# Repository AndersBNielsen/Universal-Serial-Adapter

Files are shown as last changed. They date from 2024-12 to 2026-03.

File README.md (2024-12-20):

# Universal-Serial-Adapter

## Hackable USB-C UART RS232 Adapter

The **Universal Serial Adapter** is an open-source hardware project designed to bridge USB-C, RS232, and TTL communication. This fully assembled adapter is packed with features tailored for advanced prototyping, embedded development, and system debugging.  

Make one yourself or <a href="https://www.imania.dk/product_info.php?cPath=204&products_id=7224&language=en">buy one here</a>

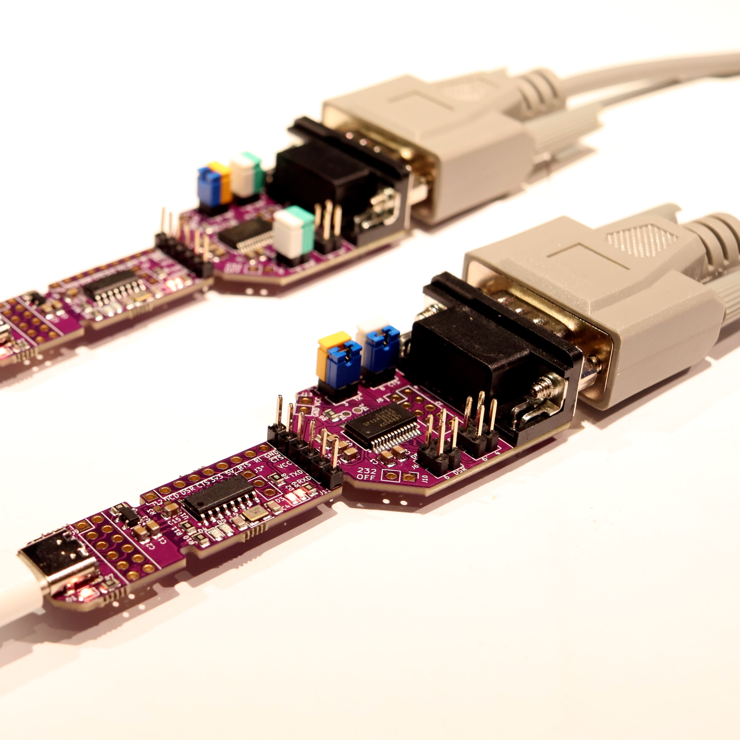
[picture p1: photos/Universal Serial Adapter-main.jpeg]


## **Technical Summary**  

### **Key Features**  
- **USB-C to RS232 Interface**  
  - USB-C (female) connector to DSUB9 RS232 (male) port.  
  - Supports bidirectional communication between modern USB-C devices and RS232 hardware.  

- **TTL Signal Breakouts**  
  - TTL RX, TX, and control signal pins exposed for easy interfacing with UART-based systems.  

- **Signal Polarity Configuration**  
  - RS232 RX, TX, and control signals configurable using 2.54mm header jumpers:  
    - **Horizontal jumper placement**: Straight connection.  
    - **Vertical jumper placement**: Crossed connection.  

- **USB-C Line Breakouts**  
  - Access to USB-C data lines for advanced custom applications.  

- **3.3V Linear Regulator**  
  - Integrated 3.3V linear regulator for powering external circuits.  

### **Core Components**  
- **WCH CH340G**: USB-to-UART bridge IC for reliable USB communication.  
- **SP3243**: TTL-to-RS232 transceiver IC for robust RS232 signaling.  

### **Customization and Modifications**  
- Advanced features such as additional breakout options or alternate configurations may require soldering or cutting traces on the PCB.  
- Preinstalled components include:  
  - USB-C connector  
  - DSUB9 RS232 connector  
  - UART header  
  - Configuration jumper blocks  
- Open to further modification for specific use cases.  

### **Open-Source Design**  
- Designed in **KiCAD 8**, with all source files available for inspection and modification.  
- Licensed under an open-source hardware license, encouraging collaboration and adaptation.  
- Repository includes:  
  - KiCAD design files.  
  - PCB layout and schematics.  
  - Bill of Materials (BOM).  

### **Applications**  
- Embedded system development.  
- Debugging and diagnostics of RS232 hardware.  
- Bridging modern USB-C devices to legacy RS232 systems.  

## **Repository Contents**  
- **/hardware/**: KiCAD project files for the PCB.  

## **Important Notes**  
- This adapter is a professional-grade tool and may require advanced soldering and modification skills for some features.  
- Enclosures, cables, and other accessories are not included.  

## **Get Started**  
Clone or download the repository to start customizing:  
```bash  
git clone https://github.com/AndersBNielsen/Universal-Serial-Adapter.git  
```
## Getting a PCB
This project is kindly sponsored by JLCPCB. They offer cheap, professional looking PCBs and super fast delivery.

Step 1: Get the gerber file zip package from the /hardware folder

Step 2: Upload to JLCPCB [https://jlcpcb.com](https://jlcpcb.com/?from=Anders_N)

Upload

Step 3: Pick your color, surface finish and order.

Select settings

Save your choice

If you want JLCPCB to assemble a board, the BOM and placement files are also in the repo. 

You can use these affiliate links to get a board for $2 and also get $60 worth of New User Coupons at: https://jlcpcb.com/?from=Anders_N

And in case you also want to order a 3D-printed case you can use this link. 
How to Get a $7 3D Printing Coupon: https://jlc3dp.com/?from=Anders_N

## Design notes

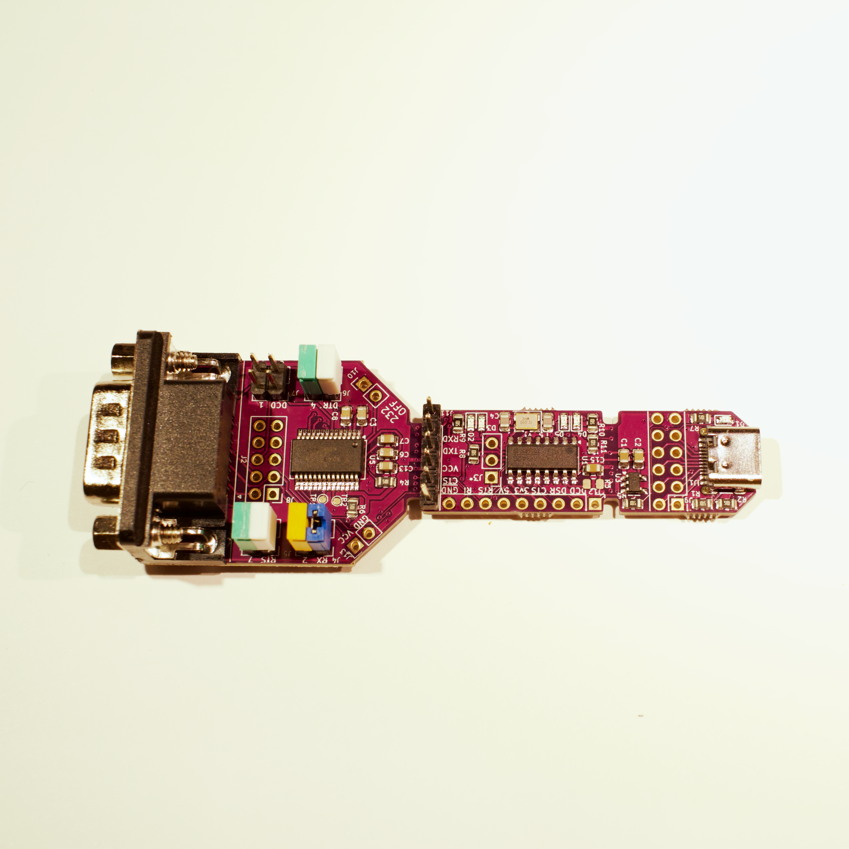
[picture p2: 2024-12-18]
photos/UniversalSerialAdapter-topflipped.jpeg

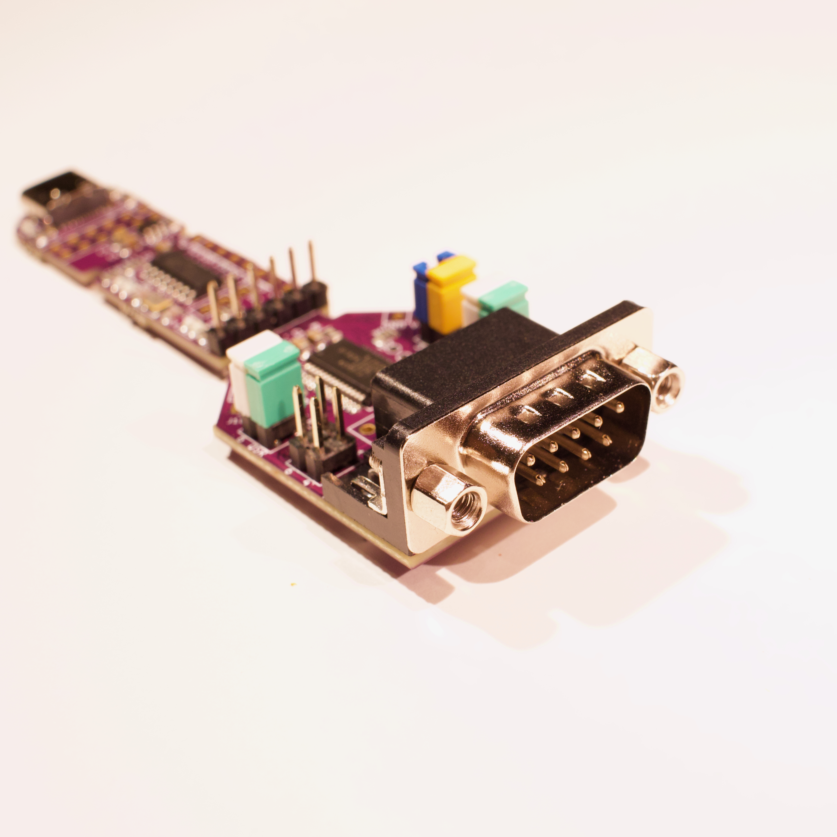
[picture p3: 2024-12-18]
photos/UniversalSerialAdapter-dsub9.jpeg

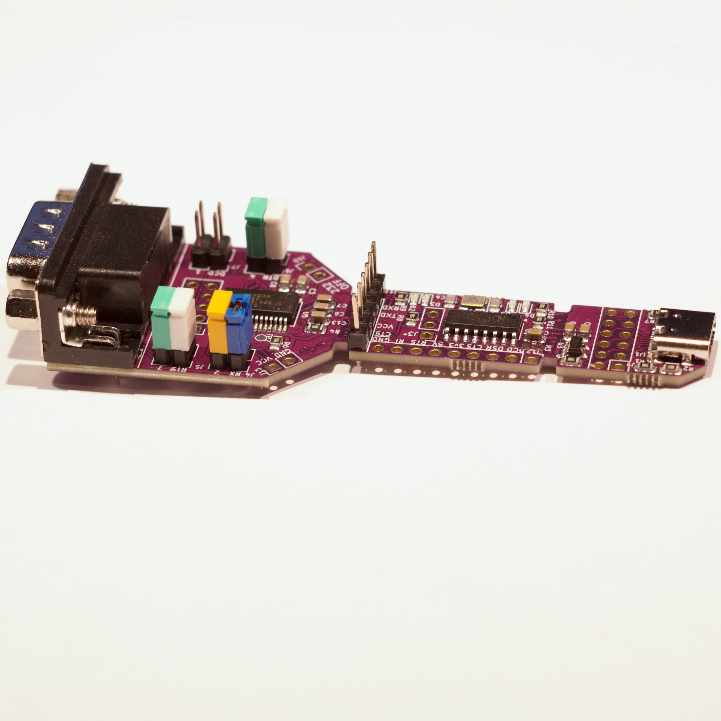
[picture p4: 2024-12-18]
photos/UniversalSerialAdapter-side.jpeg

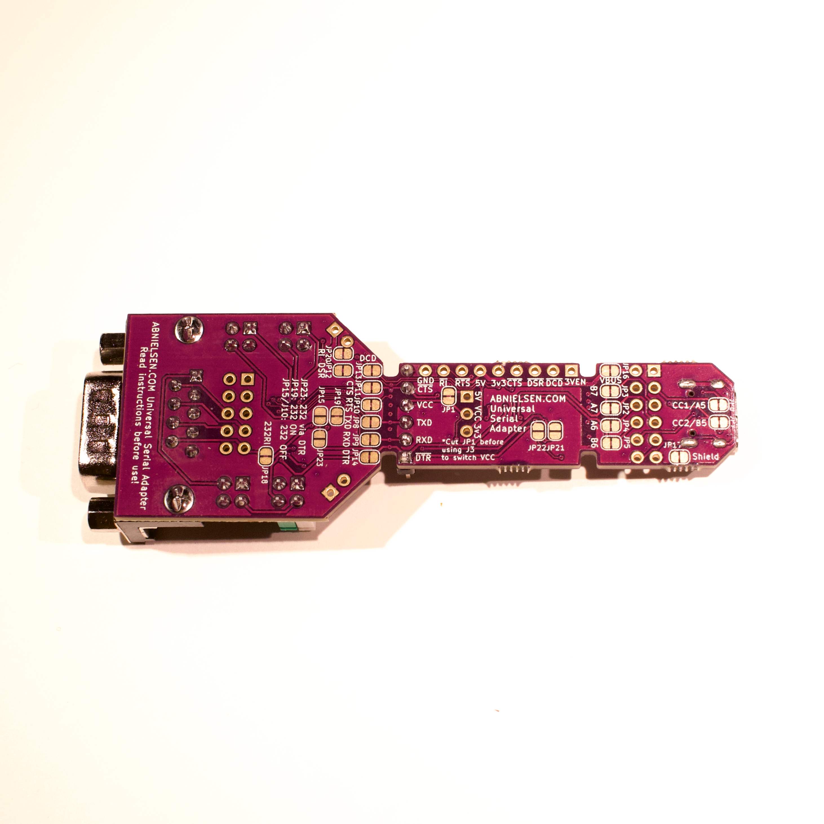
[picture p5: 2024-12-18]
photos/UniversalSerialAdapter-bottom.jpeg

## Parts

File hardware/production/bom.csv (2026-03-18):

Designator | Footprint | Quantity | Value | LCSC Part #
C1, C13, C15, C2, C3, C6, C7, C8 | 0805 | 8 | 1uF | C28323
C4, C5 | 0805 | 2 | 22p
D1 | 0603 | 1 | VBUS | C2286
D2 | 0603 | 1 | 3V3 | C2286
D3 | 0603 | 1 | VCC | C2286
D4 | 0603 | 1 | RXL | C2286
D5 | 0603 | 1 | TXL | C2286
J1 | USB_C_Receptacle_HCTL_HC-TYPE-C-16P-01A | 1 | HOST | C2894897
J11 | PinHeader_1x06_P2.54mm_Vertical | 1 | FTDI_HEADER | C37208
J13 | PinHeader_1x02_P2.54mm_Vertical | 1 | EXT_PWR
J2 | DSUB-9_Female_Horizontal_P2.77x2.84mm_EdgePinOffset7.70mm_Housed_MountingHolesOffset9.12mm | 1 | DE9_Receptacle | C19077344
J4 | PinHeader_2x02_P2.54mm_Vertical | 1 | RXTX | C492419
J5 | PinHeader_2x02_P2.54mm_Vertical | 1 | RTSCTS | C492419
J6 | PinHeader_2x02_P2.54mm_Vertical | 1 | DTRDSR | C492419
J7 | PinHeader_2x02_P2.54mm_Vertical | 1 | DCD | C492419
R1, R10, R11, R2, R4, R5, R6, R7, R8, R9 | 0805 | 10 | 5k1
TP1, TP2 | TestPoint_Pad_D1.0mm | 2 | TestPoint
U1 | SOIC-16_3.9x9.9mm_P1.27mm | 1 | CH340G | C14267
U3 | SOT-23-5 | 1 | MIC5504-3.3YM5 | C2832127
U5 | SSOP-28_5.3x10.2mm_P0.65mm | 1 | SP3243EUCY | C916165
Y1 | Crystal_SMD_3225-4Pin_3.2x2.5mm | 1 | 12MHz | C133334

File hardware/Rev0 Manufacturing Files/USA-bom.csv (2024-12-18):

Reference | Value | Datasheet | Footprint | Qty | DNP | LCSC
C1,C2,C3,C6,C7,C8,C13,C15 | 1uF | ~ | Capacitor_SMD:C_0805_2012Metric | 8 |  | C28323
C4,C5 | 22p | ~ | Capacitor_SMD:C_0805_2012Metric | 2
D1 | VBUS | ~ | LED_SMD:LED_0603_1608Metric | 1 |  | C2286
D2 | 3V3 | ~ | LED_SMD:LED_0603_1608Metric | 1 |  | C2286
D3 | VCC | ~ | LED_SMD:LED_0603_1608Metric | 1 |  | C2286
D4 | RXL | ~ | LED_SMD:LED_0603_1608Metric | 1 |  | C2286
D5 | TXL | ~ | LED_SMD:LED_0603_1608Metric | 1 |  | C2286
J1 | USB_C_Receptacle_USB2.0_16P | https://www.usb.org/sites/default/files/documents/usb_type-c.zip | Connector_USB:USB_C_Receptacle_HCTL_HC-TYPE-C-16P-01A | 1 |  | C2894897
J2 | DE9_Receptacle | ~ | Connector_Dsub:DSUB-9_Female_Horizontal_P2.77x2.84mm_EdgePinOffset7.70mm_Housed_MountingHolesOffset9.12mm | 1 |  | C19077344
J3,J8,J9,J10,J12,J13,R3 | NC | ~ | -- mixed values -- | 7
J4 | RXTX | ~ | Connector_PinHeader_2.54mm:PinHeader_2x02_P2.54mm_Vertical | 1 |  | C492419
J5 | RTSCTS | ~ | Connector_PinHeader_2.54mm:PinHeader_2x02_P2.54mm_Vertical | 1 |  | C492419
J6 | DTRDSR | ~ | Connector_PinHeader_2.54mm:PinHeader_2x02_P2.54mm_Vertical | 1 |  | C492419
J7 | DCD | ~ | Connector_PinHeader_2.54mm:PinHeader_2x02_P2.54mm_Vertical | 1 |  | C492419
J11 | UART | ~ | Connector_PinHeader_2.54mm:PinHeader_1x06_P2.54mm_Vertical | 1
R1,R2,R4,R5,R6,R7,R8,R9,R10,R11 | 5k1 | ~ | Resistor_SMD:R_0805_2012Metric | 10
TP1,TP2 | TestPoint | ~ | TestPoint:TestPoint_Pad_D1.0mm | 2
U1 | CH340G | http://www.datasheet5.com/pdf-local-2195953 | Package_SO:SOIC-16_3.9x9.9mm_P1.27mm | 1 |  | C14267
U3 | MIC5504-3.3YM5 | http://ww1.microchip.com/downloads/en/DeviceDoc/MIC550X.pdf | Package_TO_SOT_SMD:SOT-23-5 | 1 |  | C2832127
U5 | SP3243EUCY |  | Package_SO:SSOP-28_5.3x10.2mm_P0.65mm | 1 |  | C916165
Y1 | 12MHz | ~ | Crystal:Crystal_SMD_3225-4Pin_3.2x2.5mm | 1 |  | C133334

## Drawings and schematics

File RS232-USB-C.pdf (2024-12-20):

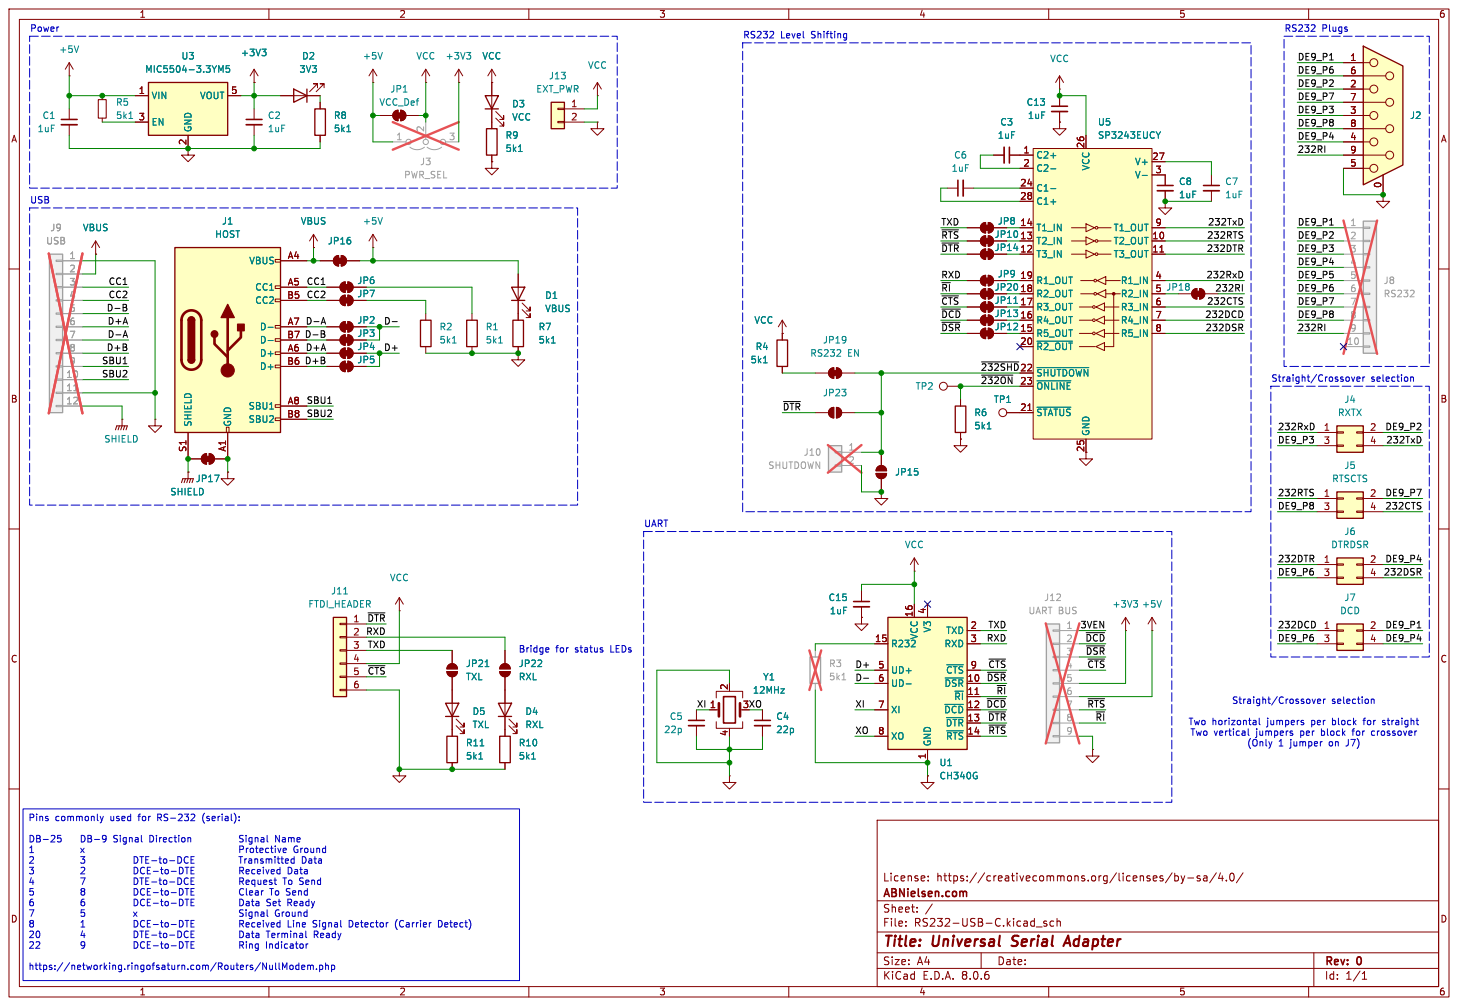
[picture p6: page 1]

4 UD+ 5 UD- 6 XI 7 XO 8 ~{CTS}9 Y1

1 ~{DSR} 10 ~{RI} 11 ~{DCD} 12 ~{DTR} 13 ~{RTS} 14 R232 15 VCC 16 TXD 2 RXD 3 V3

4 UD+ 5 UD- 6 XI 7 XO 8 ~{CTS}9 U1 CH340G

License: https://creativecommons.org/licenses/by-sa/4.0/
Id: 1/1 Title: Universal Serial Adapter File: RS232-USB-C.kicad_sch Sheet: / ABNielsen.com

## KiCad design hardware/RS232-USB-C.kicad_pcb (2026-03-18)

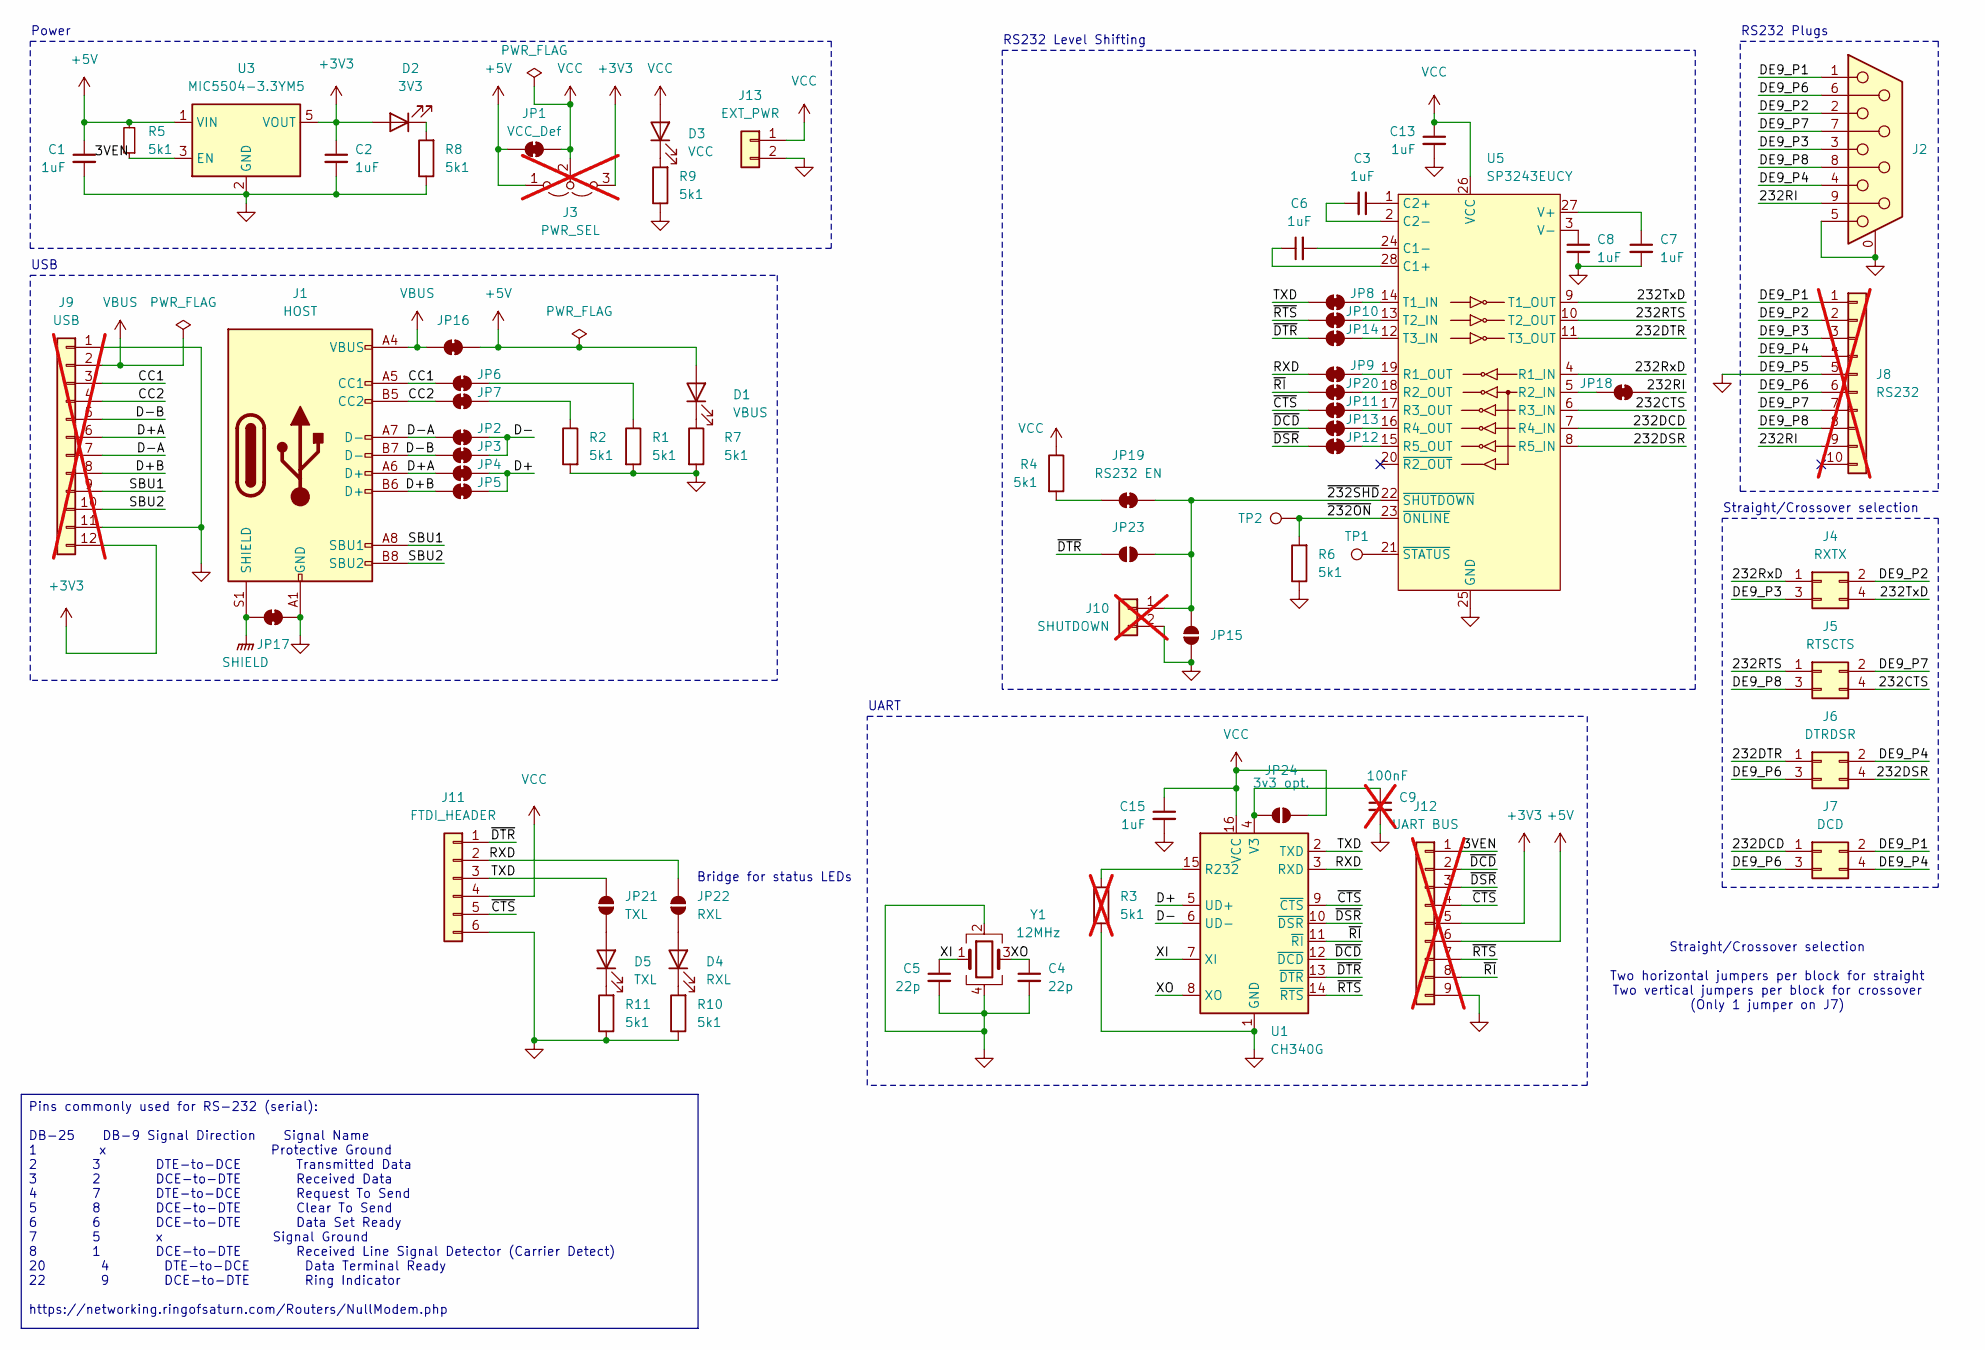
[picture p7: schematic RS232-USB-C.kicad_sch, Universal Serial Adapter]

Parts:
C1, C2, C3, C6, C7, C8, C13, C15: 1uF; C_0805_2012Metric; LCSC C28323
C4, C5: 22p; C_0805_2012Metric
C9: 100nF; C_0805_2012Metric; LCSC C28323; not fitted
D1: VBUS; LED_0603_1608Metric; LCSC C2286
D2: 3V3; LED_0603_1608Metric; LCSC C2286
D3: VCC; LED_0603_1608Metric; LCSC C2286
D4: RXL; LED_0603_1608Metric; LCSC C2286
D5: TXL; LED_0603_1608Metric; LCSC C2286
J1: HOST; USB_C_Receptacle_HCTL_HC-TYPE-C-16P-01A; LCSC C2894897
J2: DE9_Receptacle; DSUB-9_Female_Horizontal_P2.77x2.84mm_EdgePinOffset7.70mm_H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; LCSC C19077344
J3: PWR_SEL; PinHeader_1x03_P2.54mm_Vertical; not fitted
J4: RXTX; PinHeader_2x02_P2.54mm_Vertical; LCSC C492419
J5: RTSCTS; PinHeader_2x02_P2.54mm_Vertical; LCSC C492419
J6: DTRDSR; PinHeader_2x02_P2.54mm_Vertical; LCSC C492419
J7: DCD; PinHeader_2x02_P2.54mm_Vertical; LCSC C492419
J8: RS232; PinHeader_2x05_P2.54mm_Vertical; not fitted
J9: USB; PinHeader_2x06_P2.54mm_Vertical; not fitted
J10: SHUTDOWN; PinHeader_1x02_P2.54mm_Vertical; not fitted
J11: FTDI_HEADER; PinHeader_1x06_P2.54mm_Vertical; LCSC C37208
J12: UART BUS; PinHeader_1x09_P2.54mm_Vertical; not fitted
J13: EXT_PWR; PinHeader_1x02_P2.54mm_Vertical
JP1: VCC_Def; SolderJumper-2_P1.3mm_Bridged_RoundedPad1.0x1.5mm
JP2: A7; SolderJumper-2_P1.3mm_Bridged_RoundedPad1.0x1.5mm
JP3: B7; SolderJumper-2_P1.3mm_Bridged_RoundedPad1.0x1.5mm
JP4: A6; SolderJumper-2_P1.3mm_Bridged_RoundedPad1.0x1.5mm
JP5: B6; SolderJumper-2_P1.3mm_Bridged_RoundedPad1.0x1.5mm
JP6: CC1/A5; SolderJumper-2_P1.3mm_Bridged_RoundedPad1.0x1.5mm
JP7: CC2/B5; SolderJumper-2_P1.3mm_Bridged_RoundedPad1.0x1.5mm
JP8: TXD; SolderJumper-2_P1.3mm_Bridged_RoundedPad1.0x1.5mm
JP9: RXD; SolderJumper-2_P1.3mm_Bridged_RoundedPad1.0x1.5mm
JP10: RTS; SolderJumper-2_P1.3mm_Bridged_RoundedPad1.0x1.5mm
JP11: CTS; SolderJumper-2_P1.3mm_Bridged_RoundedPad1.0x1.5mm
JP12: DSR; SolderJumper-2_P1.3mm_Bridged_RoundedPad1.0x1.5mm
JP13: DCD; SolderJumper-2_P1.3mm_Bridged_RoundedPad1.0x1.5mm
JP14: DTR; SolderJumper-2_P1.3mm_Bridged_RoundedPad1.0x1.5mm
JP15, JP23: RS232 Shutdown; SolderJumper-2_P1.3mm_Open_RoundedPad1.0x1.5mm
JP16: VBUS; SolderJumper-2_P1.3mm_Bridged_RoundedPad1.0x1.5mm
JP17: Shield; SolderJumper-2_P1.3mm_Bridged_RoundedPad1.0x1.5mm
JP18: 232RI; SolderJumper-2_P1.3mm_Bridged_RoundedPad1.0x1.5mm
JP19: RS232 EN; SolderJumper-2_P1.3mm_Bridged_RoundedPad1.0x1.5mm
JP20: RI; SolderJumper-2_P1.3mm_Bridged_RoundedPad1.0x1.5mm
JP21: TXL; SolderJumper-2_P1.3mm_Open_RoundedPad1.0x1.5mm
JP22: RXL; SolderJumper-2_P1.3mm_Open_RoundedPad1.0x1.5mm
JP24: 3v3 opt.; SolderJumper-2_P1.3mm_Open_RoundedPad1.0x1.5mm
R1, R2, R4, R5, R6, R7, R8, R9, R10, R11: 5k1; R_0805_2012Metric
R3: 5k1; R_0805_2012Metric; not fitted
TP1, TP2: TestPoint; TestPoint_Pad_D1.0mm
U1: CH340G; SOIC-16_3.9x9.9mm_P1.27mm; LCSC C14267
U3: MIC5504-3.3YM5; SOT-23-5; LCSC C2832127
U5: SP3243EUCY; SSOP-28_5.3x10.2mm_P0.65mm; LCSC C916165
Y1: 12MHz; Crystal_SMD_3225-4Pin_3.2x2.5mm; LCSC C133334

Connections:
+3V3: C2.1, D2.2 (A), J3.3 (B), J9.12, J12.5, U3.5 (VOUT)
+5V: C1.1, D1.2 (A), J3.1 (A), J12.6, JP1.1 (A), JP16.2 (B), R5.2, U3.1 (VIN)
/3VEN: J12.1, R5.1, U3.3 (EN)
/232CTS: J5.4, U5.6 (R3_IN)
/232DCD: J7.1, U5.7 (R4_IN)
/232DSR: J6.4, U5.8 (R5_IN)
/232DTR: J6.1, U5.11 (T3_OUT)
/232RI: J2.9, J8.9, JP18.2 (B)
/232RTS: J5.1, U5.10 (T2_OUT)
/232RxD: J4.1, U5.4 (R1_IN)
/232TxD: J4.4, U5.9 (T1_OUT)
/CC1: J1.A5 (CC1), J9.3, JP6.1 (A)
/CC2: J1.B5 (CC2), J9.4, JP7.2 (B)
/D+: JP4.2 (B), JP5.2 (B), U1.5 (UD+)
/D+A: J1.A6 (D+), J9.6, JP4.1 (A)
/D+B: J1.B6 (D+), J9.8, JP5.1 (A)
/D-: JP2.2 (B), JP3.2 (B), U1.6 (UD-)
/D-A: J1.A7 (D-), J9.7, JP2.1 (A)
/D-B: J1.B7 (D-), J9.5, JP3.1 (A)
/DE9_P1: J2.1, J7.2, J8.1
/DE9_P2: J2.2, J4.2, J8.2
/DE9_P3: J2.3, J4.3, J8.3
/DE9_P4: J2.4, J6.2, J7.4, J8.4
/DE9_P6: J2.6, J6.3, J7.3, J8.6
/DE9_P7: J2.7, J5.2, J8.7
/DE9_P8: J2.8, J5.3, J8.8
/RXD: J11.2, JP9.1 (A), JP22.1 (A), U1.3 (RXD)
/SBU1: J1.A8 (SBU1), J9.9
/SBU2: J1.B8 (SBU2), J9.10
/TXD: J11.3, JP8.1 (A), JP21.1 (A), U1.2 (TXD)
/XI: C5.1, U1.7 (XI), Y1.1
/XO: C4.1, U1.8 (XO), Y1.3
/~232ON: R6.2, TP2.1, U5.23 (~ONLINE)
/~232SHD: J10.1, JP15.2 (B), JP19.2 (B), JP23.1 (A), U5.22 (~SHUTDOWN)
/~CTS: J11.5, J12.4, JP11.1 (A), U1.9 (~CTS)
/~DCD: J12.2, JP13.1 (A), U1.12 (~DCD)
/~DSR: J12.3, JP12.1 (A), U1.10 (~DSR)
/~DTR: J11.1, JP14.1 (A), JP23.2 (B), U1.13 (~DTR)
/~RI: J12.8, JP20.1 (A), U1.11 (~RI)
/~RTS: J12.7, JP10.1 (A), U1.14 (~RTS)
GND: C1.2, C2.2, C4.2, C5.2, C7.2, C8.2, C9.2, C13.2, C15.2, J1.A1 (GND), J1.A12 (GND), J1.B1 (GND), J1.B12 (GND), J2.0 (PAD), J2.5, J8.5, J9.1, J9.11, J10.2, J11.6, J12.9, J13.2, JP15.1 (A), JP17.2 (B), R1.2, R2.2, R3.1, R6.1, R7.2, R8.1, R9.1, R10.1, R11.1, U1.1 (GND), U3.2 (GND), U5.25 (GND), Y1.2, Y1.4
unnamed: D1.1 (K), R7.1
unnamed: D2.1 (K), R8.2
unnamed: D3.1 (K), R9.2
unnamed: D4.2 (A), JP22.2 (B)
unnamed: D4.1 (K), R10.2
unnamed: D5.2 (A), JP21.2 (B)
unnamed: D5.1 (K), R11.2
unnamed: JP6.2 (B), R1.1
unnamed: JP7.1 (A), R2.1
unnamed: JP8.2 (B), U5.14 (T1_IN)
unnamed: JP9.2 (B), U5.19 (R1_OUT)
unnamed: JP10.2 (B), U5.13 (T2_IN)
unnamed: JP11.2 (B), U5.17 (R3_OUT)
unnamed: JP12.2 (B), U5.15 (R5_OUT)
unnamed: JP13.2 (B), U5.16 (R4_OUT)
unnamed: JP14.2 (B), U5.12 (T3_IN)
unnamed: JP18.1 (A), U5.5 (R2_IN)
unnamed: JP19.1 (A), R4.2
unnamed: JP20.2 (B), U5.18 (R2_OUT)
unnamed: C9.1, JP24.1 (A), U1.4 (V3)
unnamed: R3.2, U1.15 (R232)
unnamed: C6.1, U5.28 (C1+)
unnamed: C6.2, U5.24 (C1-)
unnamed: C3.1, U5.1 (C2+)
unnamed: C3.2, U5.2 (C2-)
unnamed: C7.1, U5.27 (V+)
unnamed: C8.1, U5.3 (V-)
unnamed: TP1.1, U5.21 (~STATUS)
SHIELD: J1.S1 (SHIELD), JP17.1 (A)
VBUS: J1.A4 (VBUS), J1.A9 (VBUS), J1.B4 (VBUS), J1.B9 (VBUS), J9.2, JP16.1 (A)
VCC: C13.1, C15.1, D3.2 (A), J3.2 (C), J11.4, J13.1, JP1.2 (B), JP24.2 (B), R4.1, U1.16 (VCC), U5.26 (VCC)

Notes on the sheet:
Bridge for status LEDs
Power
RS232 Plugs
Straight/Crossover selection Two horizontal jumpers per block for straight Two vertical jumpers per block for crossover (Only 1 jumper on J7)
UART
USB
Straight/Crossover selection
RS232 Level Shifting
Pins commonly used for RS-232 (serial): DB-25 DB-9 Signal Direction Signal Name 1 x Protective Ground 2 3 DTE-to-DCE Transmitted Data 3 2 DCE-to-DTE Received Data 4 7 DTE-to-DCE Request To Send 5 8 DCE-to-DTE Clear To Send 6 6 DCE-to-DTE Data Set Ready 7 5 x Signal Ground 8 1 DCE-to-DTE Received Li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

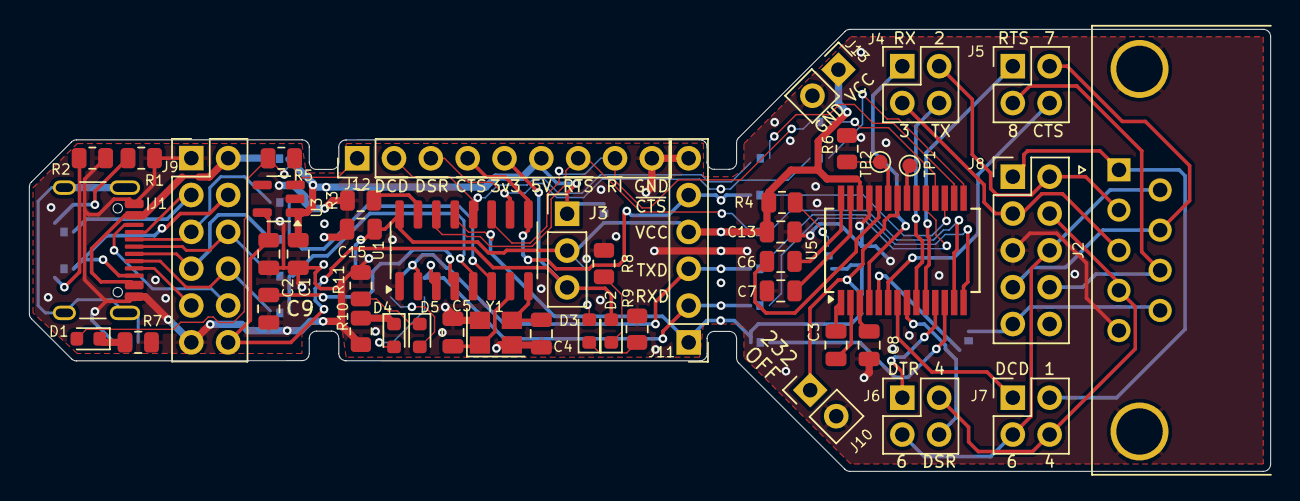
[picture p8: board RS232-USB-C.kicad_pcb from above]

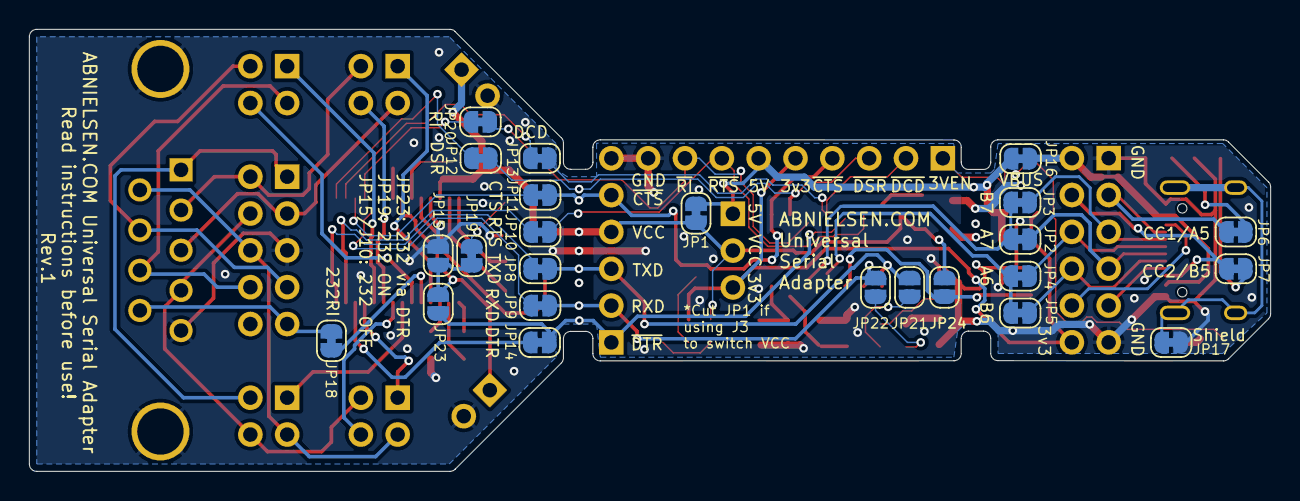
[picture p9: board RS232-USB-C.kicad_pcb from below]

Board: 2 copper layers, 85.6 x 30.5 mm, 70 parts (24 on the bottom side), 72 nets.

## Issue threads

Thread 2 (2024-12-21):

More correct application of 3V3

caitlynrw, 2024-12-21:
The CH340G has an internal 3V3 regulator for driving its USB transceiver. Right now it's output pin is just floating. The datasheet recommends what to do with it

What I've done on a similar board is have it tied to the 3V3 rail

Snippet from datasheet
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

AndersBNielsen, 2024-12-21:
I think my worry was that V3 might be connected to VCC internally, shorting 5V and 3v3 when using 5V. It's one of those things I thought I better test in practice.
You're probably totally right - I didn't have the guts to do the first untested production run like that though.
I'll leave this open for testing.

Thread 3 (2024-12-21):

ESD Protection

caitlynrw, 2024-12-21:
It might be worth considering adding some ESD protection ICs to this as its designed to be used out in the open. The [USBLC6-2](https://www.st.com/resource/en/datasheet/usblc6-2.pdf) is normally a good bet for USB2 as that bus can be particularly sensitive.

Probably not as important is protection of the RS232 port which could be done using a series of [ESD\*\*\*6](https://www.st.com/resource/en/datasheet/esdaxxxp6.pdf) chips if desired.

Another thing to consider with the RS232 port is bad or incorrect wiring on the other side; these could be dead shorts or voltages wayy out of spec, this could be mitigated with some clamping diodes if desired. For low pin count clamping I normally use some [BAS40-04](https://assets.nexperia.com/documents/data-sheet/BAS40-04.pdf)s but I've also seen people use TVS arrays in place for higher pin counts.

None of this particularly matters just trying to "oops"-proof the board 😅

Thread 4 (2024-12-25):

File LICENSE absents

vazhnov, 2024-12-25:
Hello!

I found this project from https://hackaday.com/2024/12/25/break-me-off-a-piece-of-that-open-source-serial-adapter/

I see a phrase "Licensed under an open-source hardware license, encouraging collaboration and adaptation" in the README, but I can't find the license information in the repository.

Also I see a comment in `hardware/RS232-USB-C.kicad_sch`:
> License: https://creativecommons.org/licenses/by-sa/4.0/

Could you please create the `LICENSE` file? (it is possible to generate it with "Add file" button, which is located near green "<> Code" button)

AndersBNielsen, 2024-12-27:
commit 3e01764795425fdef7adac4ed61f9a98ba00f130

vazhnov, 2024-12-28:
@AndersBNielsen, thank you!

Closed 2024-12-27.

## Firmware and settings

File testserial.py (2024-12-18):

#!/bin/python3
import serial
import serial.tools.list_ports
import time
import random
import sys

# Constants
#BAUD_RATES = [9600, 19200, 38400, 57600, 115200, 230400, 460800, 921600, 1500000, 2000000]  # Test baud rates
BAUD_RATES = [57600, 115200, 230400, 460800, 921600, 1500000, 2000000, 3000000]  # Test baud rates
BLOCK_SIZE = 1024  # 1KB of data

def detect_serial_ports():
    """Detect serial ports starting with 'cu.usbserial'."""
    ports = [port.device for port in serial.tools.list_ports.comports() if "cu.usbserial" in port.device]
    if len(ports) < 2:
        print("Error: At least two 'cu.usbserial' ports are required.")
        sys.exit(1)
    return ports[0], ports[1]

def generate_random_data(size):
    """Generate a block of random data."""
    return bytearray(random.getrandbits(8) for _ in range(size))

def test_baud_rate(tx_port, rx_port, baud_rate, data):
    """Test a given baud rate by sending and receiving a block of data."""
    try:
        with serial.Serial(tx_port, baud_rate, timeout=2) as tx_ser, \
             serial.Serial(rx_port, baud_rate, timeout=2) as rx_ser:
            print(f"Testing baud rate: {baud_rate} bps")

            # Clear buffers
            tx_ser.reset_input_buffer()
            tx_ser.reset_output_buffer()
            rx_ser.reset_input_buffer()
            rx_ser.reset_output_buffer()

            # Send data
            start_time = time.time()
            tx_ser.write(data)
            tx_ser.flush()  # Ensure all data is sent

            # Receive data
            received_data = rx_ser.read(len(data))
            end_time = time.time()

            # Check for errors
            errors = sum(1 for a, b in zip(data, received_data) if a != b)
            elapsed_time = end_time - start_time
            throughput = (len(data) * 8) / elapsed_time if elapsed_time > 0 else 0  # Bits per second

            print(f"  Data size: {len(data)} bytes")
            print(f"  Time taken: {elapsed_time:.2f} seconds")
            print(f"  Throughput: {throughput:.2f} bps")
            print(f"  Errors: {errors}\n")
            return errors == 0

    except serial.SerialException as e:
        print(f"Serial error at baud rate {baud_rate}: {e}")
        return False

if __name__ == "__main__":
    # Auto-detect serial ports
    tx_port, rx_port = detect_serial_ports()
    print(f"Detected TX port: {tx_port}")
    print(f"Detected RX port: {rx_port}")

    # Generate random data
    random_data = generate_random_data(BLOCK_SIZE)

    print("\nStarting serial link test...\n")
    for baud_rate in BAUD_RATES:
        success = test_baud_rate(tx_port, rx_port, baud_rate, random_data)
        if not success:
            print(f"Test failed at baud rate {baud_rate}.")
            sys.exit(1)

    print("All baud rates tested successfully!")

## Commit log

2024-12-18 Photos and schematic PDF
2024-12-20 Tidy schematic
    - Replaced criss-crossed wires with labels between IC/connectors
    - Removed jumper 'values' where wasn't really needed
    - repositioned references/values where hard to read
    - gave components room to 'breathe'
    - changed to regular (compared to small) components in most places to avoid cramping
    - moved components around to be close to their logical section
    - updated some symbols to be more standard/correct
    - replaced 'NC' components to regularly labelled ones marked as DNP
    - fixed sch->pcb linking on J3
    - organized schematic into logical blocks
    - uncommited the lockfile
    [RS232-USB-C.kicad_pcb, RS232-USB-C.kicad_sch]
2024-12-20 Update schematic PDF
2026-03-18 Rev 1
    [RS232-USB-C.kicad_pcb, RS232-USB-C.kicad_sch, bom.csv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]
